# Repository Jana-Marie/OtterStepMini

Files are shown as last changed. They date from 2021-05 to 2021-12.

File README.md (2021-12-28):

# OtterStepMini

OtterStepMini is a user friendly, up to 48V 10A stepper-motor-driver. It can be controlled via RS485 or USB-CDC and also comes with a 100W USB-PD input, for extra convinience on stepper-motor testing and for small desktop applications (e.g. 3D-scanner turntable).

**The board has not been tested and should not be ordered yet.**

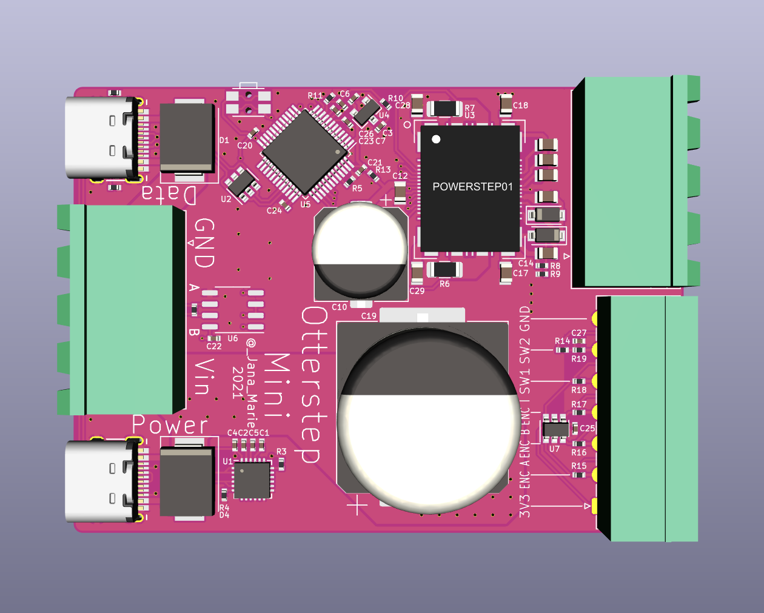
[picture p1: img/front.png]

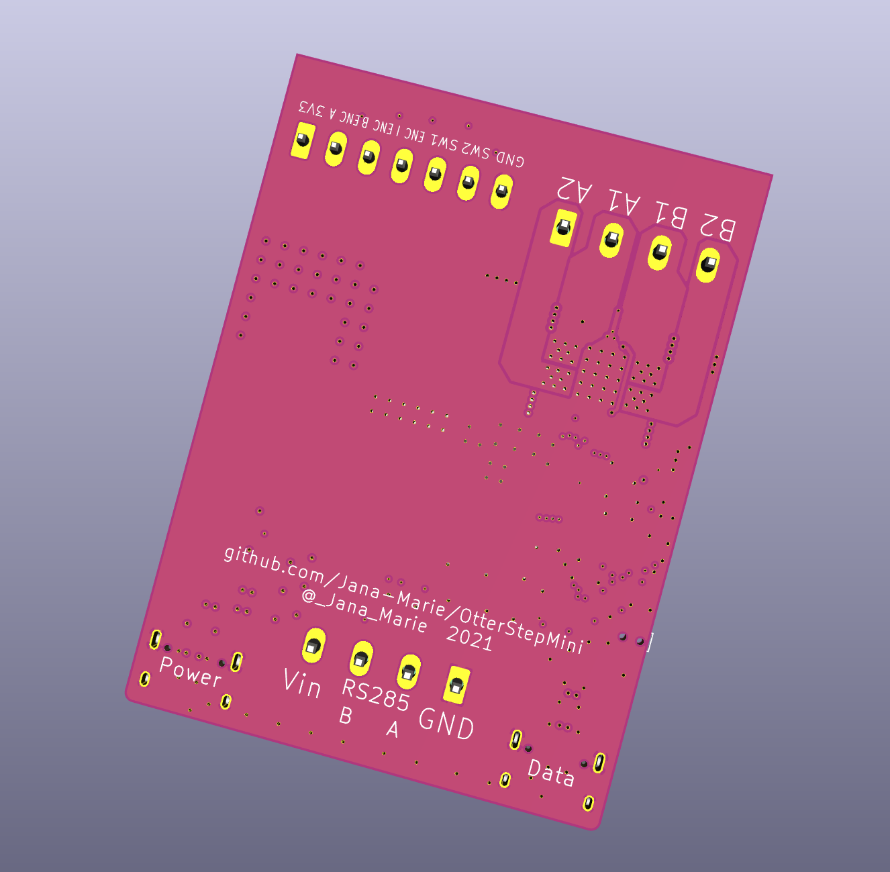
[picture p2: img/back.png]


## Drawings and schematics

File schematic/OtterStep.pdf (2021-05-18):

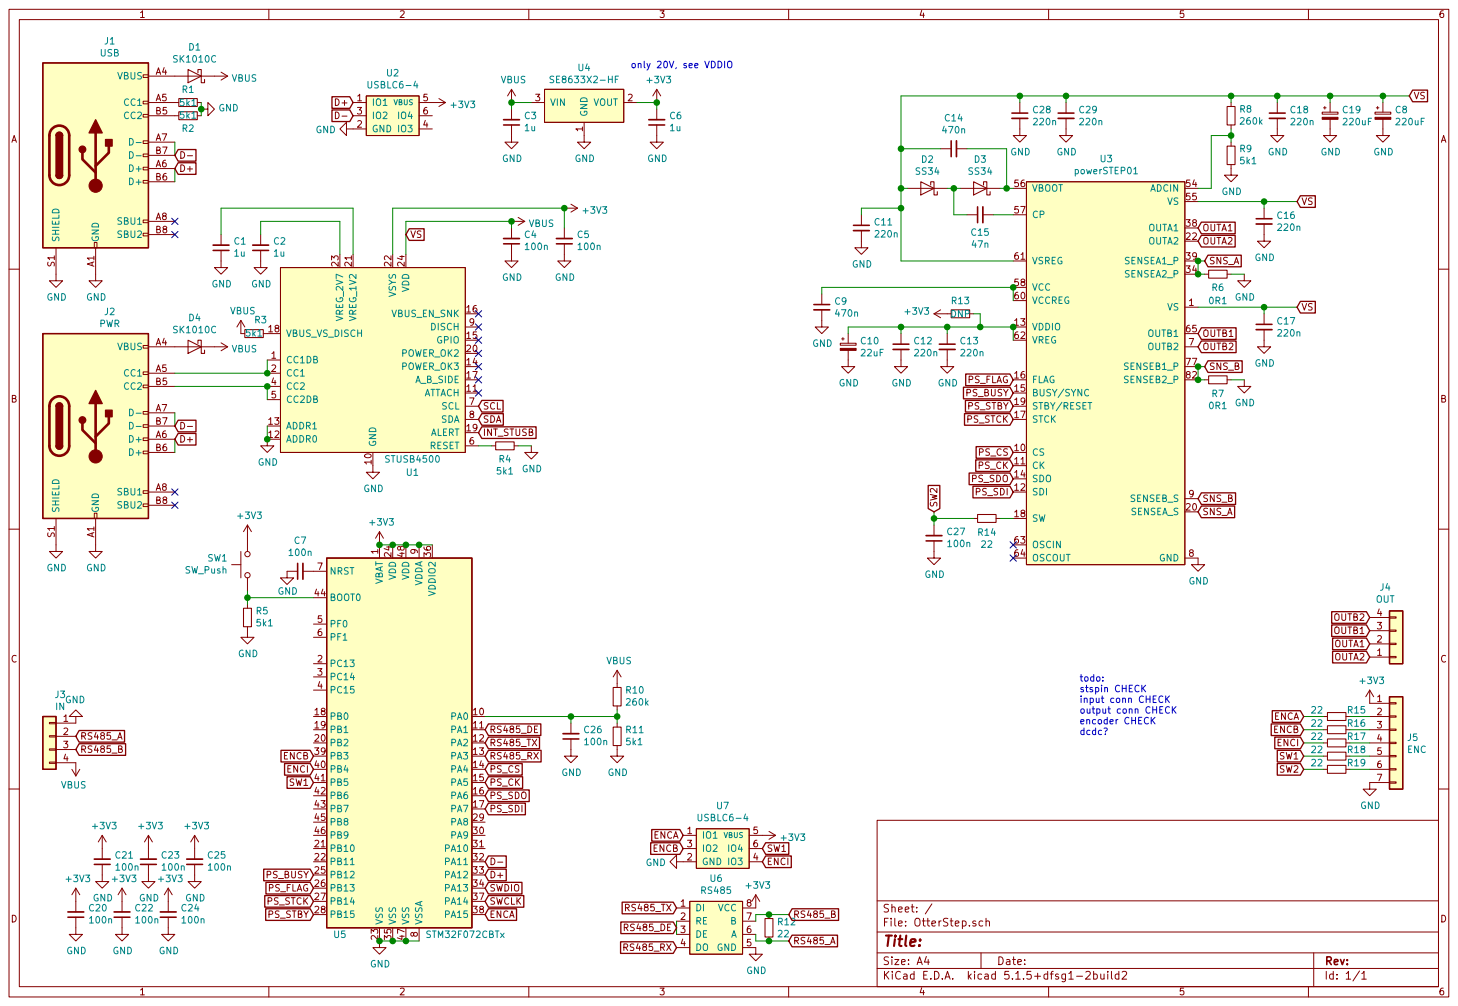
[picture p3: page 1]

1 PA0 10 PA1 11 PA2 12 PA3 13 PA4 14 PA5 15 PA6 16 PA7 17 PB0 18 PB1 19 PC13 2 PB2 20 PB10 21 PB11 22 VSS 23 VDD 24 PB12 25 PB13 26 PB14 27 PB15 28 PA8 29 PC14 3 PA9 30 PA10 31 PA11 32 PA12 33 PA13 34 VSS 35 VDDIO2 36 PA14 37 PA15 38 PB3 39 PC15 4 PB4 40 PB5 41 PB6 42 PB7 43 BOOT0 44 PB8 45 PB9 46 VSS 47 VDD 48 PF0 5 PF1 6 NRST 7 VSSA

File: OtterStep.sch Sheet: /
Id: 1/1 Title:

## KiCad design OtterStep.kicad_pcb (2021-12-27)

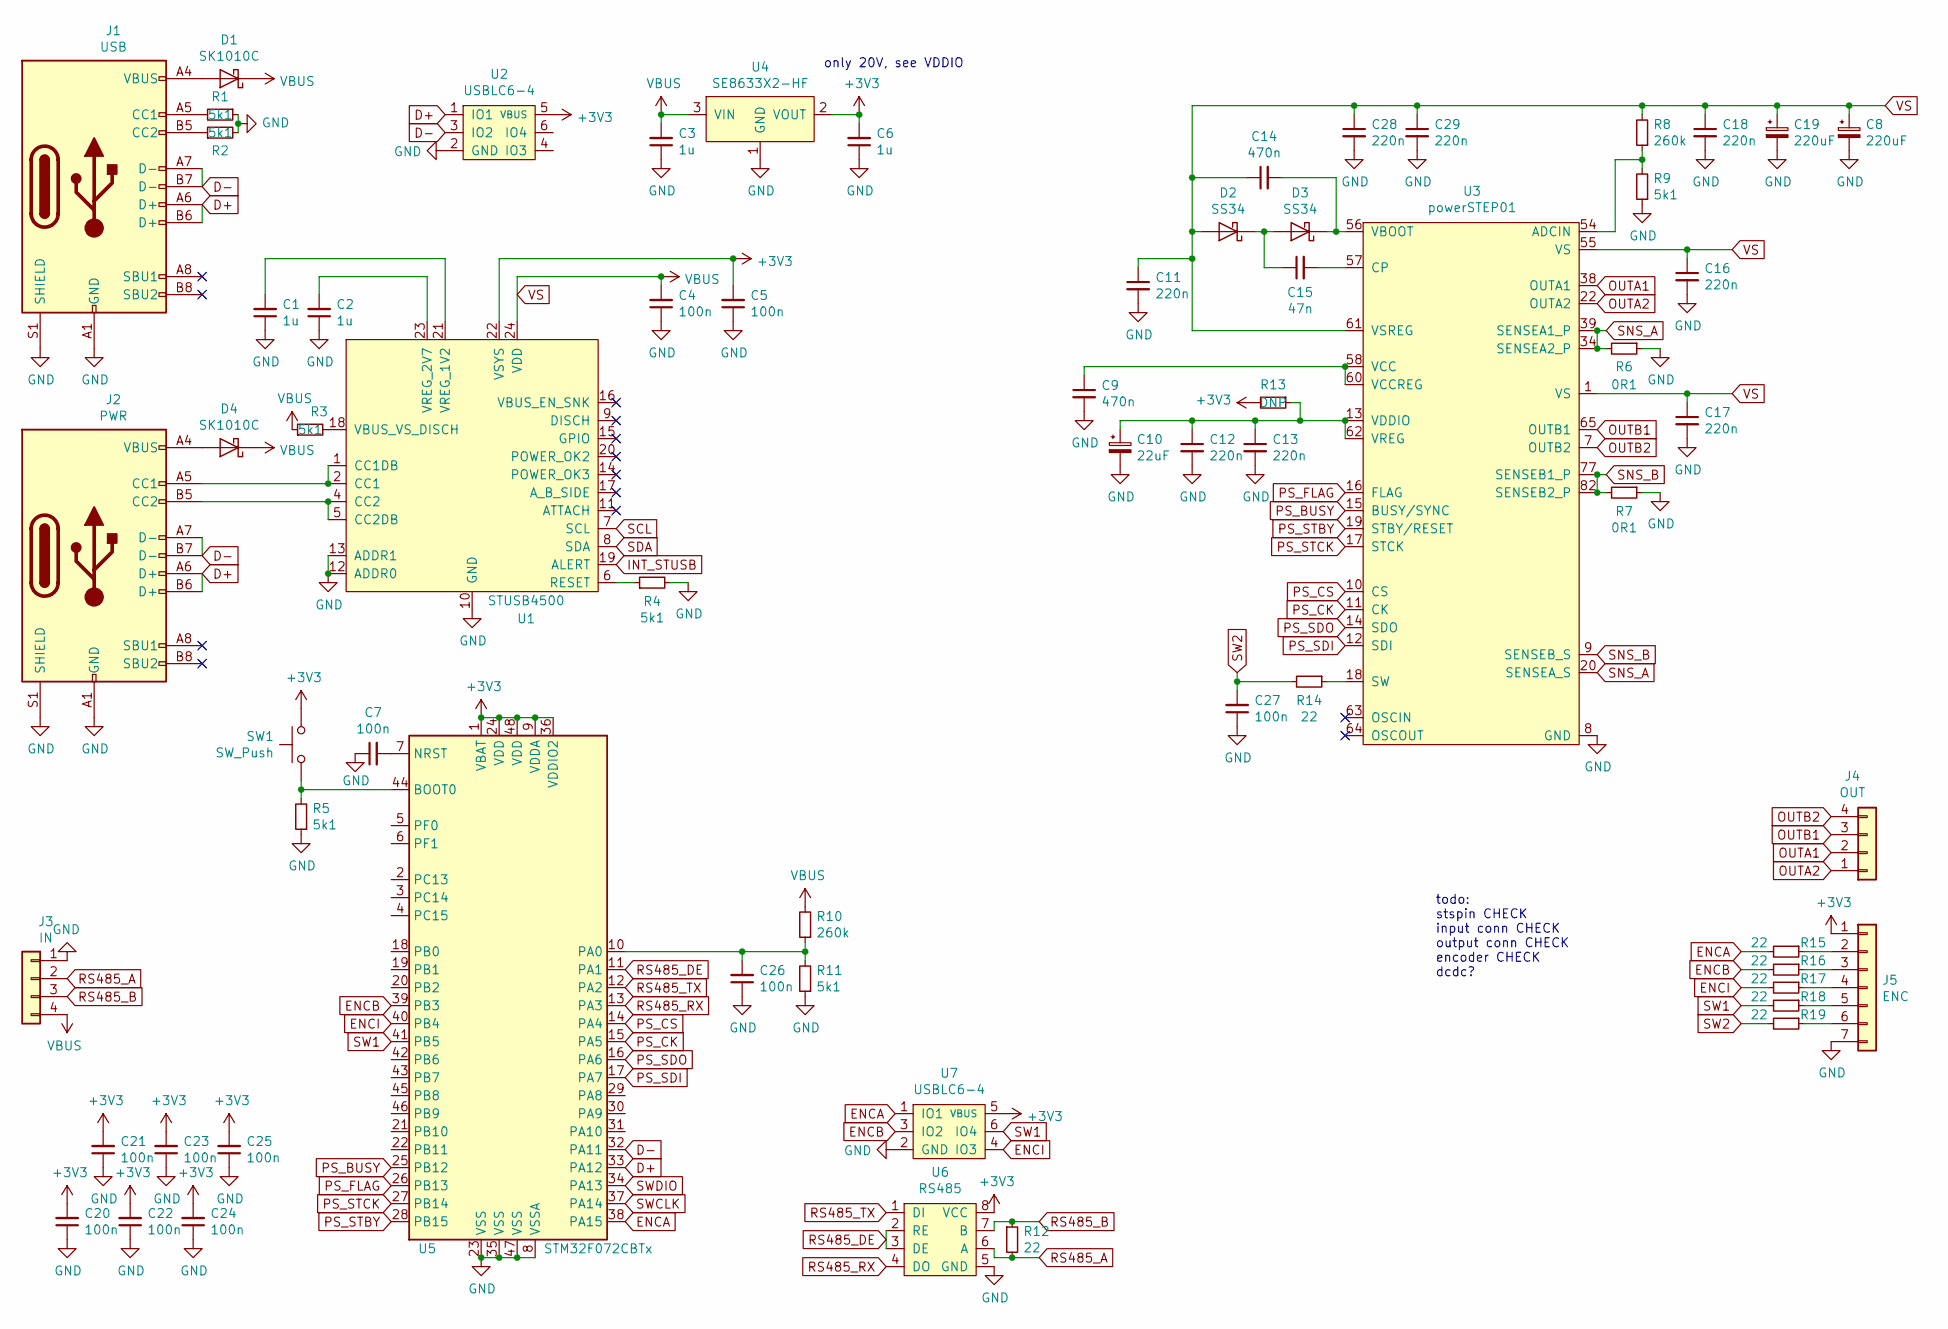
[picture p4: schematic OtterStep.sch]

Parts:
C1, C2, C3, C6: 1u; C_0402
C4, C5, C7, C20, C21, C22, C23, C24, C25, C26, C27: 100n; C_0402
C8, C19: 220uF; CP_Elec_18x17.5
C9, C14: 470n; C_0805
C10: 22uF; CP_Elec_10x10
C11, C12, C13, C16, C17, C18, C28, C29: 220n; C_0805
C15: 47n; C_0805
D1, D4: SK1010C; D_SMC
D2, D3: SS34; D_SOD-123
J1: USB; USB-C 16Pin
J2: PWR; USB-C 16Pin
J3: IN; PhoenixContact_MSTBA_2,5_4-G_1x04_P5.00mm_Horizontal
J4: OUT; PhoenixContact_MSTBA_2,5_4-G_1x04_P5.00mm_Horizontal
J5: ENC; PhoenixContact_MC_1,5_7-G-3.5_1x07_P3.50mm_Horizontal
R1, R2, R3, R4, R5, R9, R11: 5k1; R_0402
R6, R7: 0R1; R_1206_3216Metric
R8, R10: 260k; R_0402
R12, R14, R15, R16, R17, R18, R19: 22; R_0402
R13: DNP; R_0402
SW1: SW_Push; SW_SPST_EVQP7C
U1: STUSB4500; QFN-24-1EP_4x4mm_P0.5mm_EP2.7x2.7mm
U2, U7: USBLC6-4; SOT-23-6
U3: powerSTEP01
U4: SE8633X2-HF; SOT-23
U5: STM32F072CBTx; LQFP-48_7x7mm_P0.5mm
U6: RS485; SO-8_3.9x4.9mm_P1.27mm

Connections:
+3V3: C5.2, C6.2, C20.2, C21.2, C22.2, C23.2, C24.2, C25.2, J5.1, R13.2, SW1.2, U1.22 (VSYS), U2.5 (VBUS), U4.2 (VOUT), U5.1 (VBAT), U5.9 (VDDA), U5.24 (VDD), U5.36 (VDDIO2), U5.48 (VDD), U6.8 (VCC), U7.5 (VBUS)
D+: J1.A6 (D+), J1.B6 (D+), J2.A6 (D+), J2.B6 (D+), U2.1 (IO1), U5.33 (PA12)
D-: J1.A7 (D-), J1.B7 (D-), J2.A7 (D-), J2.B7 (D-), U2.3 (IO2), U5.32 (PA11)
ENCA: R15.2, U5.38 (PA15), U7.1 (IO1)
ENCB: R16.2, U5.39 (PB3), U7.3 (IO2)
ENCI: R17.2, U5.40 (PB4), U7.4 (IO3)
GND: C1.1, C2.1, C3.1, C4.1, C5.1, C6.1, C7.1, C8.2, C9.2, C10.2, C11.2, C12.2, C13.2, C16.2, C17.2, C18.2, C19.2, C20.1, C21.1, C22.1, C23.1, C24.1, C25.1, C26.1, C27.1, C28.2, C29.2, J1.A1 (GND), J1.A12 (GND), J1.B1 (GND), J1.B12 (GND), J1.S1 (SHIELD), J2.A1 (GND), J2.A12 (GND), J2.B1 (GND), J2.B12 (GND), J2.S1 (SHIELD), J3.1, J5.7, R1.1, R2.2, R4.2, R5.1, R6.1, R7.1, R9.1, R11.1, U1.10 (GND), U1.12 (ADDR0), U1.13 (ADDR1), U1.25 (GND), U2.2 (GND), U3.8 (GND), U3.21 (GND), U3.59 (GND), U3.EPAD9 (GND), U4.1 (GND), U5.8 (VSSA), U5.23 (VSS), U5.35 (VSS), U5.47 (VSS), U6.5 (GND), U7.2 (GND)
INT_STUSB: U1.19 (ALERT)
unnamed: C1.2, U1.21 (VREG_1V2)
unnamed: C2.2, U1.23 (VREG_2V7)
unnamed: C7.2, U5.7 (NRST)
unnamed: C9.1, U3.58 (VCC), U3.60 (VCCREG)
unnamed: C10.1, C12.1, C13.1, R13.1, U3.13 (VDDIO), U3.62 (VREG)
unnamed: C14.2, D3.1 (K), U3.56 (VBOOT)
unnamed: C15.1, D2.1 (K), D3.2 (A)
unnamed: C15.2, U3.57 (CP)
unnamed: C26.2, R10.1, R11.2, U5.10 (PA0)
unnamed: D1.2 (A), J1.A4 (VBUS), J1.A9 (VBUS), J1.B4 (VBUS), J1.B9 (VBUS)
unnamed: D4.2 (A), J2.A4 (VBUS), J2.A9 (VBUS), J2.B4 (VBUS), J2.B9 (VBUS)
unnamed: J1.A5 (CC1), R1.2
unnamed: J1.B5 (CC2), R2.1
unnamed: J2.A5 (CC1), U1.1 (CC1DB), U1.2 (CC1)
unnamed: J2.B5 (CC2), U1.4 (CC2), U1.5 (CC2DB)
unnamed: J5.2, R15.1
unnamed: J5.3, R16.1
unnamed: J5.4, R17.1
unnamed: J5.5, R18.1
unnamed: J5.6, R19.1
unnamed: R3.2, U1.18 (VBUS_VS_DISCH)
unnamed: R4.1, U1.6 (RESET)
unnamed: R5.2, SW1.1, U5.44 (BOOT0)
unnamed: R8.1, R9.2, U3.54 (ADCIN)
unnamed: R14.1, U3.18 (SW)
OUTA1: J4.2, U3.38 (OUTA1), U3.42 (OUTA1), U3.53 (OUTA1), U3.EPAD4 (OUTA1)
OUTA2: J4.1, U3.22 (OUTA2), U3.33 (OUTA2), U3.37 (OUTA2), U3.EPAD3 (OUTA2)
OUTB1: J4.3, U3.65 (OUTB1), U3.76 (OUTB1), U3.80 (OUTB1), U3.EPAD7 (OUTB1)
OUTB2: J4.4, U3.7 (OUTB2), U3.81 (OUTB2), U3.85 (OUTB2), U3.EPAD8 (OUTB2)
PS_BUSY: U3.15 (BUSY/SYNC), U5.25 (PB12)
PS_CK: U3.11 (CK), U5.15 (PA5)
PS_CS: U3.10 (CS), U5.14 (PA4)
PS_FLAG: U3.16 (FLAG), U5.26 (PB13)
PS_SDI: U3.12 (SDI), U5.17 (PA7)
PS_SDO: U3.14 (SDO), U5.16 (PA6)
PS_STBY: U3.19 (STBY/RESET), U5.28 (PB15)
PS_STCK: U3.17 (STCK), U5.27 (PB14)
RS485_A: J3.2, R12.2, U6.6 (A)
RS485_B: J3.3, R12.1, U6.7 (B)
RS485_DE: U5.11 (PA1), U6.2 (RE), U6.3 (DE)
RS485_RX: U5.13 (PA3), U6.4 (DO)
RS485_TX: U5.12 (PA2), U6.1 (DI)
SCL: U1.7 (SCL)
SDA: U1.8 (SDA)
SNS_A: R6.2, U3.20 (SENSEA_S), U3.34 (SENSEA2_P), U3.39 (SENSEA1_P)
SNS_B: R7.2, U3.9 (SENSEB_S), U3.77 (SENSEB1_P), U3.82 (SENSEB2_P)
SW1: R18.2, U5.41 (PB5), U7.6 (IO4)
SW2: C27.2, R14.2, R19.2
SWCLK: U5.37 (PA14)
SWDIO: U5.34 (PA13)
VS: C3.2, C4.2, C8.1, C11.1, C14.1, C16.1, C17.1, C18.1, C19.1, C28.1, C29.1, D1.1 (K), D2.2 (A), D4.1 (K), J3.4, R3.1, R8.2, R10.2, U1.24 (VDD), U3.1 (VS), U3.23 (VS), U3.43 (VS), U3.55 (VS), U3.61 (VSREG), U3.66 (VS), U4.3 (VIN)

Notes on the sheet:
todo: stspin CHECK input conn CHECK output conn CHECK encoder CHECK dcdc?
only 20V, see VDDIO

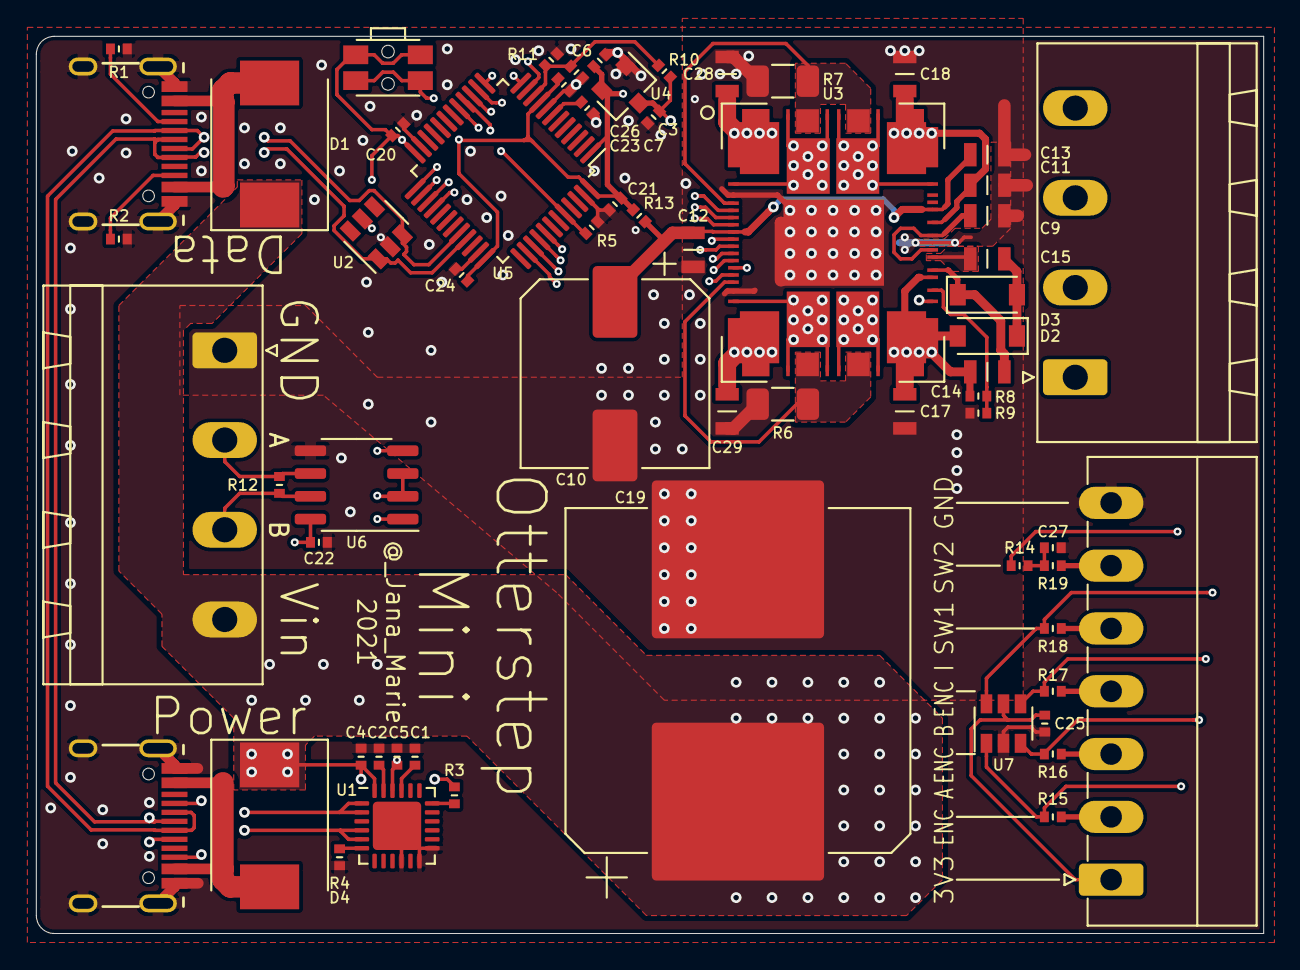
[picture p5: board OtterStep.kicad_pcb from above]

Board: 4 copper layers, 68.4 x 50.0 mm, 63 parts (0 on the bottom side), 54 nets.

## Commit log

2021-07-17 updated files
    [OtterStep-B_Cu.gbl, OtterStep-B_Mask.gbs, OtterStep-B_Paste.gbp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]
2021-12-27 changed silk
    [OtterStep-B_Cu.gbl, OtterStep-B_Mask.gbs, OtterStep-B_Paste.gbp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]
